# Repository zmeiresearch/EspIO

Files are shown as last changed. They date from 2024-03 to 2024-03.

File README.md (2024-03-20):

# EspIO

This is a simple carrier board for ESP32-DevKitC (30-pin version) that implements a number of I/O channels:
- 8 Digital Inputs with protection and solder-time input range selection. Default values in schematic are for 12V input
  but this can easily be extended up to ~200V by proper resistor selection.
- 8 Digital Outputs, either buffered push-pull or Open Collector with on-board pull-ups.
- RS-485 serial interface

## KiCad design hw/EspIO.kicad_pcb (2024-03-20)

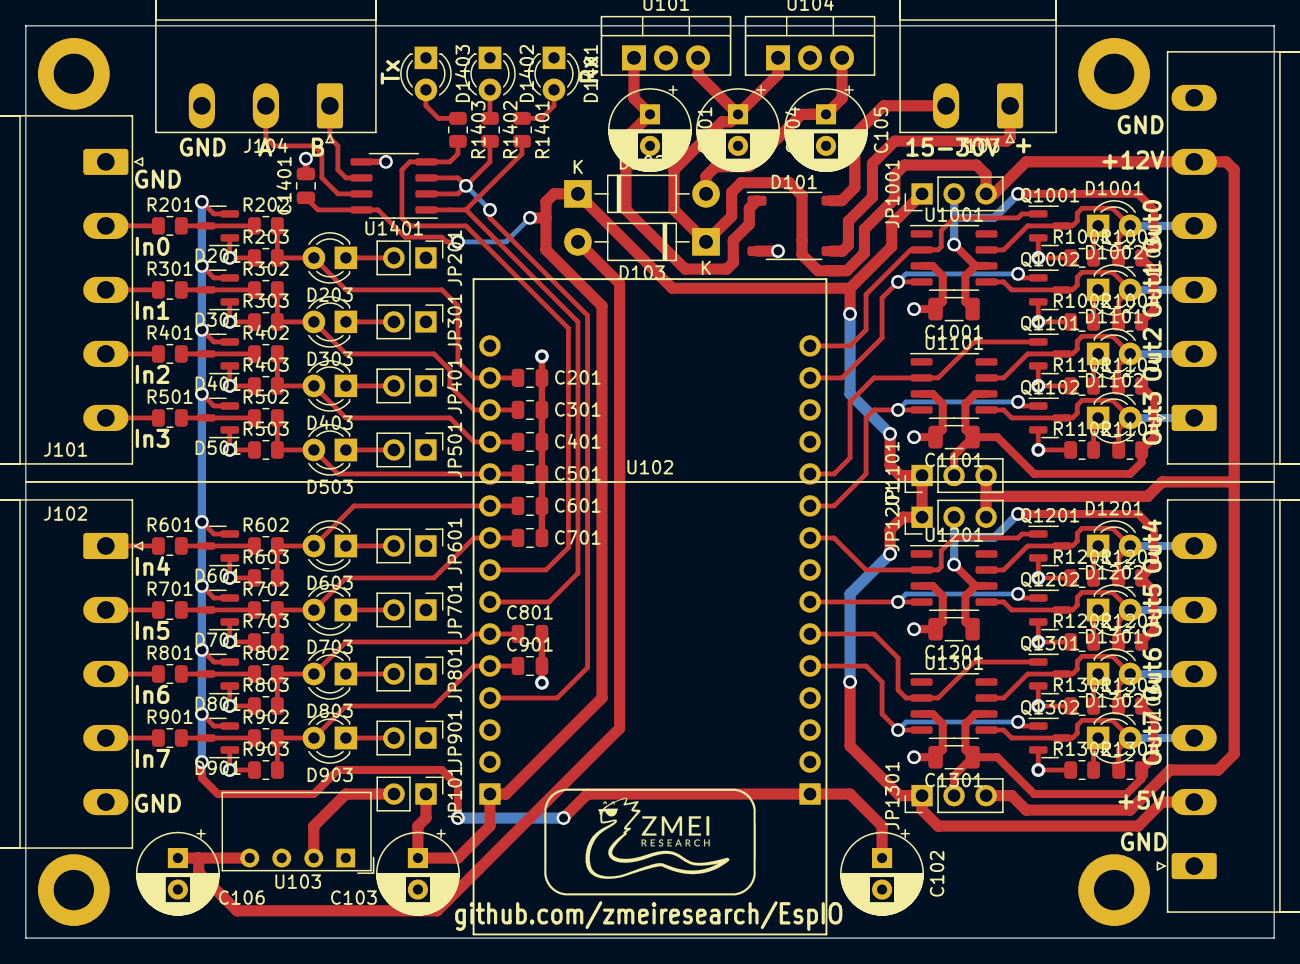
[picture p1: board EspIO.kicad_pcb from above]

Board: 2 copper layers, 99.1 x 72.4 mm, 132 parts (0 on the bottom side), 78 nets.

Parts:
C101, C102, C103, C104, C105: 100uF/16V; CP_Radial_D6.3mm_P2.50mm
C106: 22uF/25V; CP_Radial_D6.3mm_P2.50mm
C201, C301, C401, C501, C601, C701, C801, C901: 10nF; C_0805_2012Metric
C1001, C1101, C1201, C1301: 10nF; C_1206_3216Metric
C1401: 100nF; C_0805_2012Metric
D101: MDB10S; TSSOP-4_4.4x5mm_P4mm
D102, D103: 1N5818; D_DO-41_SOD81_P10.16mm_Horizontal
D201, D301, D401, D501, D601, D701, D801, D901: BAT54S; SOT-23
D203, D303, D403, D503, D603, D703, D803, D903, D1001, D1002, D1101, D1102, D1201, D1202, D1301, D1302: LED; LED_D3.0mm
D1401: Rx; LED_D3.0mm
D1402: TE; LED_D3.0mm
D1403: Tx; LED_D3.0mm
H101, H102, H103, H104: MountingHole; MountingHole_3.2mm_M3_ISO7380_Pad
J101, J102: 2EDGR-5.08-05P-14-00AH; PhoenixContact_MSTBA_2,5_5-G-5,08_1x05_P5.08mm_Horizontal
J103: Screw_Terminal_01x02; PhoenixContact_MSTBA_2,5_2-G-5,08_1x02_P5.08mm_Horizontal
J104: Screw_Terminal_01x03; PhoenixContact_MSTBA_2,5_3-G-5,08_1x03_P5.08mm_Horizontal
J105, J106: Screw_Terminal_01x06; PhoenixContact_MSTBA_2,5_6-G-5,08_1x06_P5.08mm_Horizontal
JP101, JP201, JP301, JP401, JP501, JP601, JP701, JP801, JP901: Jumper_2_Open; PinHeader_1x02_P2.54mm_Vertical
JP1001, JP1101, JP1201, JP1301: Jumper_3_Open; PinHeader_1x03_P2.54mm_Vertical
Q1001, Q1002, Q1101, Q1102, Q1201, Q1202, Q1301, Q1302: BCR141; SOT-23
R201, R301, R401, R501, R601, R701, R801, R901: 2.2k; R_0805_2012Metric
R202, R302, R402, R502, R602, R702, R802, R902, R1001, R1002, R1003, R1004, R1101, R1102, R1103, R1104, R1201, R1202, R1203, R1204, R1301, R1302, R1303, R1304, R1401, R1402, R1403: 1k; R_0805_2012Metric
R203, R303, R403, R503, R603, R703, R803, R903: 22k; R_0805_2012Metric
U101: LM7812_TO220; TO-220-3_Vertical
U102: ESP32DevKit_30pin
U103: AM1SS-0512SJZ; Converter_DCDC_AM1SS
U104: LM7805_TO220; TO-220-3_Vertical
U1001, U1101, U1201, U1301: TC4427; SO-8_3.9x4.9mm_P1.27mm
U1401: SN75176AP; SO-8_3.9x4.9mm_P1.27mm

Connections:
+3.3V: C102.1, D201.2 (K), D301.2 (K), D401.2 (K), D501.2 (K), D601.2 (K), D701.2 (K), D801.2 (K), D901.2 (K), U102.1 (3V3)
+5V: C103.1, C1401.1, D102.1 (K), J106.2, JP101.1 (A), JP1001.1 (A), JP1101.1 (A), JP1201.1 (A), JP1301.1 (A), U102.30 (Vin), U1401.8 (VCC)
+12V: C104.1, D103.1 (K), J105.5, JP1001.3 (B), JP1101.3 (B), JP1201.3 (B), JP1301.3 (B), U101.3 (VO), U104.1 (VI)
/DI0: J101.2, R201.1
/DI0_: C201.1, D203.2 (A), R202.2, R203.2, U102.17 (SP/G36/ADC0)
/DI1: J101.3, R301.1
/DI1_: C301.1, D303.2 (A), R302.2, R303.2, U102.18 (SN/G39/ADC3)
/DI2: J101.4, R401.1
/DI2_: C401.1, D403.2 (A), R402.2, R403.2, U102.19 (G34/ADC6)
/DI3: J101.5, R501.1
/DI3_: C501.1, D503.2 (A), R502.2, R503.2, U102.20 (G35/ADC7)
/DI4: J102.1, R601.1
/DI4_: C601.1, D603.2 (A), R602.2, R603.2, U102.21 (G32/ADC4/T9)
/DI5: J102.2, R701.1
/DI5_: C701.1, D703.2 (A), R702.2, R703.2, U102.22 (G33/ADC5/T8)
/DI6: J102.3, R801.1
/DI6_: C801.1, D803.2 (A), R802.2, R803.2, U102.25 (G27/ADC17/T7)
/DI7: J102.4, R901.1
/DI7_: C901.1, D903.2 (A), R902.2, R903.2, U102.26 (G14/ADC16/T6/SPI_CLK)
/DO0: D1001.2 (A), J105.4, Q1001.3 (C), R1003.1, U1001.7 (OutA)
/DO0_: Q1001.1 (B), U102.15 (G23/VSPI_MOSI), U1001.2 (InA)
/DO1: D1002.2 (A), J105.3, Q1002.3 (C), R1004.1, U1001.5 (OutB)
/DO1_: Q1002.1 (B), U102.14 (G22/I2C_SCL), U1001.4 (InB)
/DO2: D1101.2 (A), J105.2, Q1101.3 (C), R1103.1, U1101.7 (OutA)
/DO2_: Q1101.1 (B), U102.11 (G21/I2C_SDA), U1101.2 (InA)
/DO3: D1102.2 (A), J105.1, Q1102.3 (C), R1104.1, U1101.5 (OutB)
/DO3_: Q1102.1 (B), U102.10 (G19/VSPI_MISO), U1101.4 (InB)
/DO4: D1201.2 (A), J106.6, Q1201.3 (C), R1203.1, U1201.7 (OutA)
/DO4_: Q1201.1 (B), U102.9 (G18/VSPI_SCK), U1201.2 (InA)
/DO5: D1202.2 (A), J106.5, Q1202.3 (C), R1204.1, U1201.5 (OutB)
/DO5_: Q1202.1 (B), U102.7 (G17/TX2), U1201.4 (InB)
/DO6: D1301.2 (A), J106.4, Q1301.3 (C), R1303.1, U1301.7 (OutA)
/DO6_: Q1301.1 (B), U102.6 (G16/RX2), U1301.2 (InA)
/DO7: D1302.2 (A), J106.3, Q1302.3 (C), R1304.1, U1301.5 (OutB)
/DO7_: Q1302.1 (B), U102.5 (G4/ADC010/T0), U1301.4 (InB)
/RS485/A: J104.2, U1401.7 (B)
/RS485/B: J104.1, U1401.6 (A)
/Rx: R1401.2, U102.24 (G26/ADC19/DAC2), U1401.1 (R)
/Tx: R1403.2, U102.23 (G25/ADC18/DAC1), U1401.4 (D)
/Tx/~Rx: R1402.2, U102.27 (G12/ADC15/T5/SPI_MISO), U1401.2 (~RE), U1401.3 (DE)
GND: C101.2, C102.2, C103.2, C104.2, C105.2, C106.2, C201.2, C301.2, C401.2, C501.2, C601.2, C701.2, C801.2, C901.2, C1001.2, C1101.2, C1201.2, C1301.2, C1401.2, D101.2 (-), D201.1 (A), D301.1 (A), D401.1 (A), D501.1 (A), D601.1 (A), D701.1 (A), D801.1 (A), D901.1 (A), D1401.1 (K), D1402.1 (K), D1403.1 (K), J101.1, J102.5, J104.3, J105.6, J106.1, JP201.1 (A), JP301.1 (A), JP401.1 (A), JP501.1 (A), JP601.1 (A), JP701.1 (A), JP801.1 (A), JP901.1 (A), Q1001.2 (E), Q1002.2 (E), Q1101.2 (E), Q1102.2 (E), Q1201.2 (E), Q1202.2 (E), Q1301.2 (E), Q1302.2 (E), R203.1, R303.1, R403.1, R503.1, R603.1, R703.1, R803.1, R903.1, R1001.1, R1002.1, R1101.1, R1102.1, R1201.1, R1202.1, R1301.1, R1302.1, U101.2 (GND), U102.2 (GND), U102.29 (GND), U103.1 (-Vin), U103.3 (-Vout), U104.2 (GND), U1001.3 (GND), U1101.3 (GND), U1201.3 (GND), U1301.3 (GND), U1401.5 (GND)
unnamed: C101.1, D101.1 (+), U101.1 (VI)
unnamed: C105.1, D102.2 (A), U104.3 (VO)
unnamed: C106.1, D103.2 (A), U103.4 (+Vout)
unnamed: D201.3 (COM), R201.2, R202.1
unnamed: D203.1 (K), JP201.2 (B)
unnamed: D301.3 (COM), R301.2, R302.1
unnamed: D303.1 (K), JP301.2 (B)
unnamed: D401.3 (COM), R401.2, R402.1
unnamed: D403.1 (K), JP401.2 (B)
unnamed: D501.3 (COM), R501.2, R502.1
unnamed: D503.1 (K), JP501.2 (B)
unnamed: D601.3 (COM), R601.2, R602.1
unnamed: D603.1 (K), JP601.2 (B)
unnamed: D701.3 (COM), R701.2, R702.1
unnamed: D703.1 (K), JP701.2 (B)
unnamed: D801.3 (COM), R801.2, R802.1
unnamed: D803.1 (K), JP801.2 (B)
unnamed: D901.3 (COM), R901.2, R902.1
unnamed: D903.1 (K), JP901.2 (B)
unnamed: D1001.1 (K), R1001.2
unnamed: D1002.1 (K), R1002.2
unnamed: D1101.1 (K), R1101.2
unnamed: D1102.1 (K), R1102.2
unnamed: D1201.1 (K), R1201.2
unnamed: D1202.1 (K), R1202.2
unnamed: D1301.1 (K), R1301.2
unnamed: D1302.1 (K), R1302.2
unnamed: D1401.2 (A), R1401.1
unnamed: D1402.2 (A), R1402.1
unnamed: D1403.2 (A), R1403.1
unnamed: D101.3, J103.1
unnamed: D101.4, J103.2
unnamed: JP101.2 (B), U103.2 (+Vin)
unnamed: C1001.1, JP1001.2 (C), R1003.2, R1004.2, U1001.6 (Vdd)
unnamed: C1101.1, JP1101.2 (C), R1103.2, R1104.2, U1101.6 (Vdd)
unnamed: C1201.1, JP1201.2 (C), R1203.2, R1204.2, U1201.6 (Vdd)
unnamed: C1301.1, JP1301.2 (C), R1303.2, R1304.2, U1301.6 (Vdd)
